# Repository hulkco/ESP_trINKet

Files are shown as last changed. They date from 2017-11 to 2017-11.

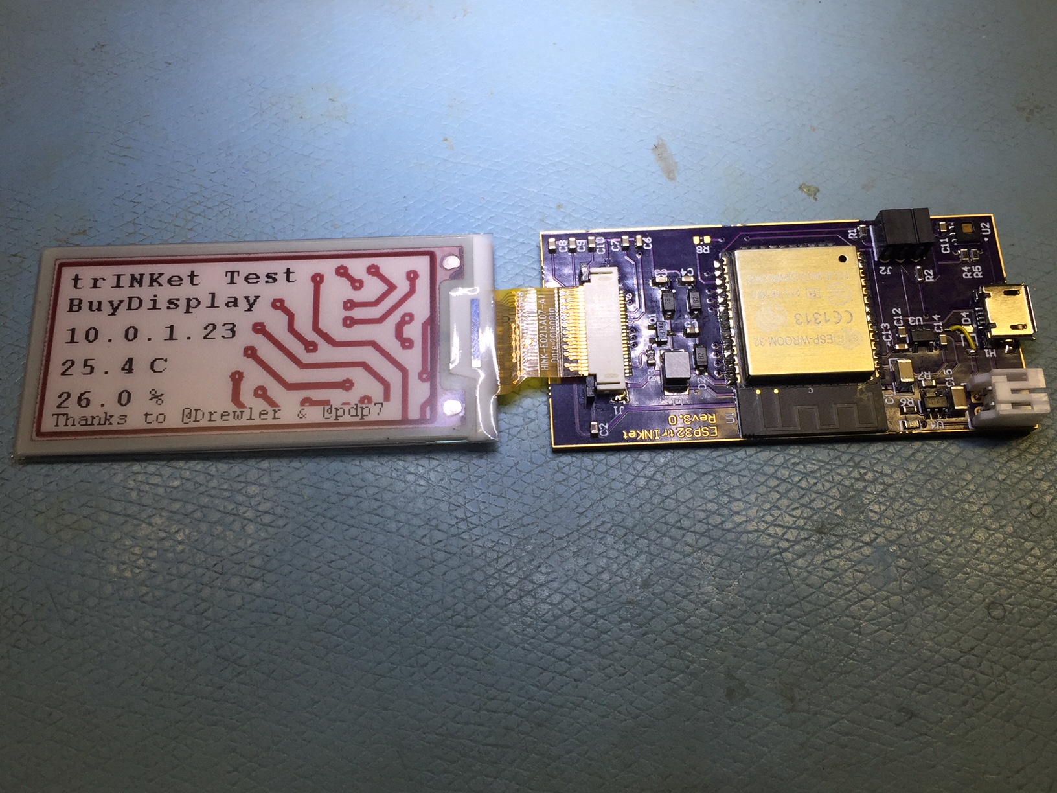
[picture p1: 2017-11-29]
Images/Assembly.JPG

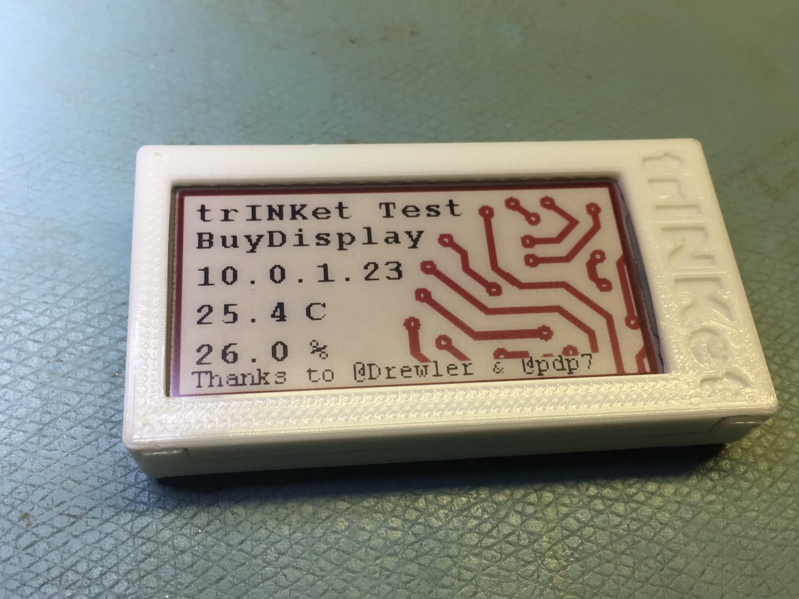
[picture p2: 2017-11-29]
Images/Display.JPG

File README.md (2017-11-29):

# ESP_trINKet
ESP32 E-Ink Developement Board

This design was an experiment using an E-Ink display. Another PCB revision is on the way that should allowing it to be powered from a battery. Right now it can only be powered using a microUSB cable.

The programmer board is located at: https://github.com/mike-rankin/ESP32_Programmer

The enclosure designed in Fusion360 is located here: https://www.thingiverse.com/thing:2675865

Special thanks to:
Drew at OSH Park for supplying the PCB @pdp7
and @drewler for re-writing the Waveshare library so it will work on the BuyDisplay hardware

The code right now does a hardware test verifying the display, sensors and wifi are functional are functional. If you manage to create something of your own I would love to see it by reaching me at @mikerankin

display

board_2

assembly

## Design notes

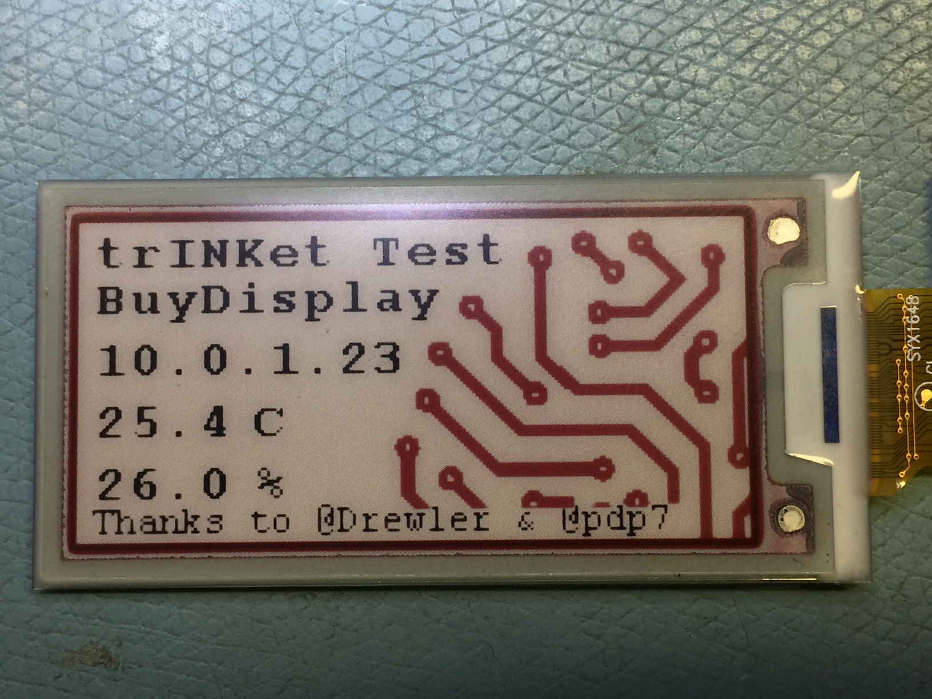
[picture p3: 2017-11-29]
Images/Bare_Display_1.JPG

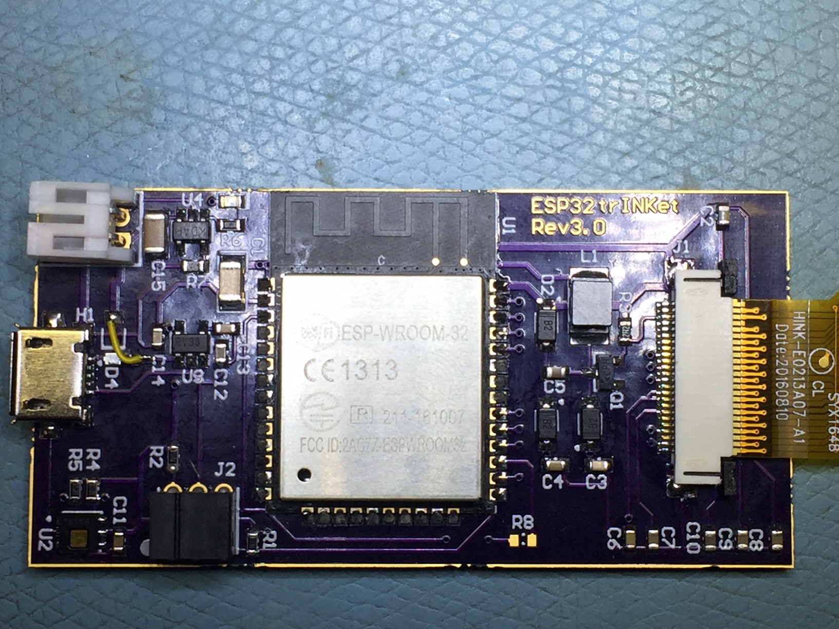
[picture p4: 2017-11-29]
Images/Board_2.JPG

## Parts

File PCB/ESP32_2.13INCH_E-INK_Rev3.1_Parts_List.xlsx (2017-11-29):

Designator | Quantity | Value | Vendor | PartNumber | Description | Manufacturer | Comment
U4 | 1 | MCP73831T-2ACI | Digi-Key | MCP73831T-2ACI/OT | Charger IC Lithium-Ion/Polymer SOT23-5 | Microchip | MCP73831T-2ACI/OT
U3 | 1 | CAT6219-330TDGT3 | Digi-Key | CAT6219-330TDGT3 | IC REG LDO 3.3V 0.5A SOT23-5 | On Semi | CAT6219-330TDGT3
U2 | 1 | 2N7002K-T1-E3 | Digi-Key | 2N7002K-T1-E3 | Humidity/Temperature Sensor | Texas Instruments | HDC1080DMBT
U1 | 1 | ESP32 | Alexpress | ESP32S | WIFI&Bluetooth |  | ESP32s
R6 | 1 | 2K | Digi-Key | ERJ-3EKF2001V | RES SMD 2K OHM 1% 1/10W 0603 | Panasonic | 2K
R4, R5 | 2 | 4.7K | Digi-Key | ERJ-PA3F4701V | RES SMD 4.7K OHM 1% 1/4W 0603 | Panasonic | 4.7K
R3 | 1 | 2.2R | Digi-Key | ERJ-3GEYJ2R2V | RES SMD 2.2 OHM 5% 1/10W 0603 | Panasonic | 2.2R
R1, R2, R7 | 3 | 10K | Digi-Key | ERJ-3EKF1002V | RES SMD 10K OHM 1% 1/10W 0603 | Panasonic | 10K
Q1 | 1 | N-CH Mosfet | Digi-Key | 2N7002K-T1-E3 | MOSFET N-CH 60V 300MA SOT-23 | Vishay Siliconix | 2N7002K-T1-E3
L1 | 1 | 68uH | Digi-Key | LQH43CN680K03L | INDUCTOR 68UH 10% 220MA 1812 | Murata | LQH43CN680K03L
J3 | 1 | Batt Connector | Digi-Key | S2B-PH-K-S(LF)(SN) | CONN HEADER PH SIDE 2POS 2MM | JST | JST
J2 | 1 | 3x2 Female Con | Digi-Key | 0872640652 | Recptacle, Female 3X2,TH, 2MM R/A | MOLEX | 3x2
J1 | 1 | 24POS Flex Con | Digi-Key | 0524352471 | CONN FFC TOP 24POS 0.50MM R/A | Molex | 24POS Flex Con
H3 | 1 | 2.13" E-INK Display | WaveShare | 13368 | WaveShare 2.13" E-INK Display | WaveShare | E-INK Display
H2 | 1 | 2.13" E-INK Display | BuyDisplay | ER-EPD0213-1 | BuyDisplay 2.13" E-INK Display | BuyDisplay | E-INK Display
H1 | 1 | Micro USB | Digi-Key | 1981584-1 | CONN RCPT MICRO USB TYPE AB | TE Connectivity | Micro USB
D5 | 1 | Red | Digi-Key | LTST-C191KRKT | LED RED CLEAR 0603 SMD | Lite-On | LED_0603
D1, D2, D3, D4 | 4 | MBR0520 | Digi-Key | MBR0520-TP | DIODE SCHOTTKY 20V 500MA SOD123 | Micro | MBR0520-TP
C15 | 1 | 10uF | Digi-Key | CL31B106KOHNNNE | CAP CER 10uF 16V 10% X7R 1206 | Samsung | 10uF
C13 | 1 | 10nF | Digi-Key | GRM188R71C103KA01D | CAP CER 0.01uF 16V X7R 0603 | Murata | 10nF
C11 | 1 | 0.1uF | Digi-Key | GRM188R71E104KA01D | CAP, 0.1uF, 25V, 0603 | Murata | 0.1uF
C6, C14 | 2 | 2.2uF | Digi-Key | GRM188R61C225KE15D | CAP CER 2.2uF 16V X5R 0603 | Murata | 2.2uF
C3, C5 | 2 | 1uF | Digi-Key | C0603C105K3RACTU | CAP CER 1UF 25V X7R 0603 | Kemet | 1uF
C2, C4, C7, C8, C9, C10, C12 | 7 | 1uF | Digi-Key | GRM188R71C105KA12D | CAP CER 1uF 16V X7R 0603, CAP CER 1UF 25V X7R 0603, CAP CER 1uF 16V X7R 0603, CAP CER 1uF 16V X7R 0603, CAP CER 1uF 16V X7R 0603, CAP CER 1uF 16V X7R 0603, CAP CER 1uF 16V X7R 0603 | Murata, Kemet, Murata, Murata, Murata, Murata, Murata | 1uF
C1 | 1 | 220uF | Aliexpress | GRM31CC80G227ME11L | CAP CER 220UF 4V X6S 1206 | Murata | 220uF

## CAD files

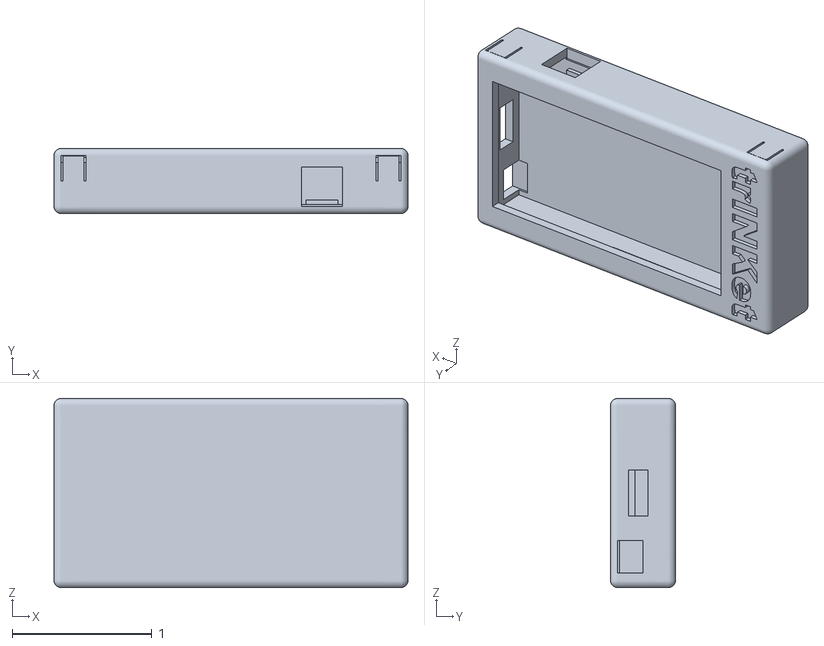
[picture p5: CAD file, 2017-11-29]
Enclosure/trINKet v45.stl
2.53 x 0.465 x 1.35

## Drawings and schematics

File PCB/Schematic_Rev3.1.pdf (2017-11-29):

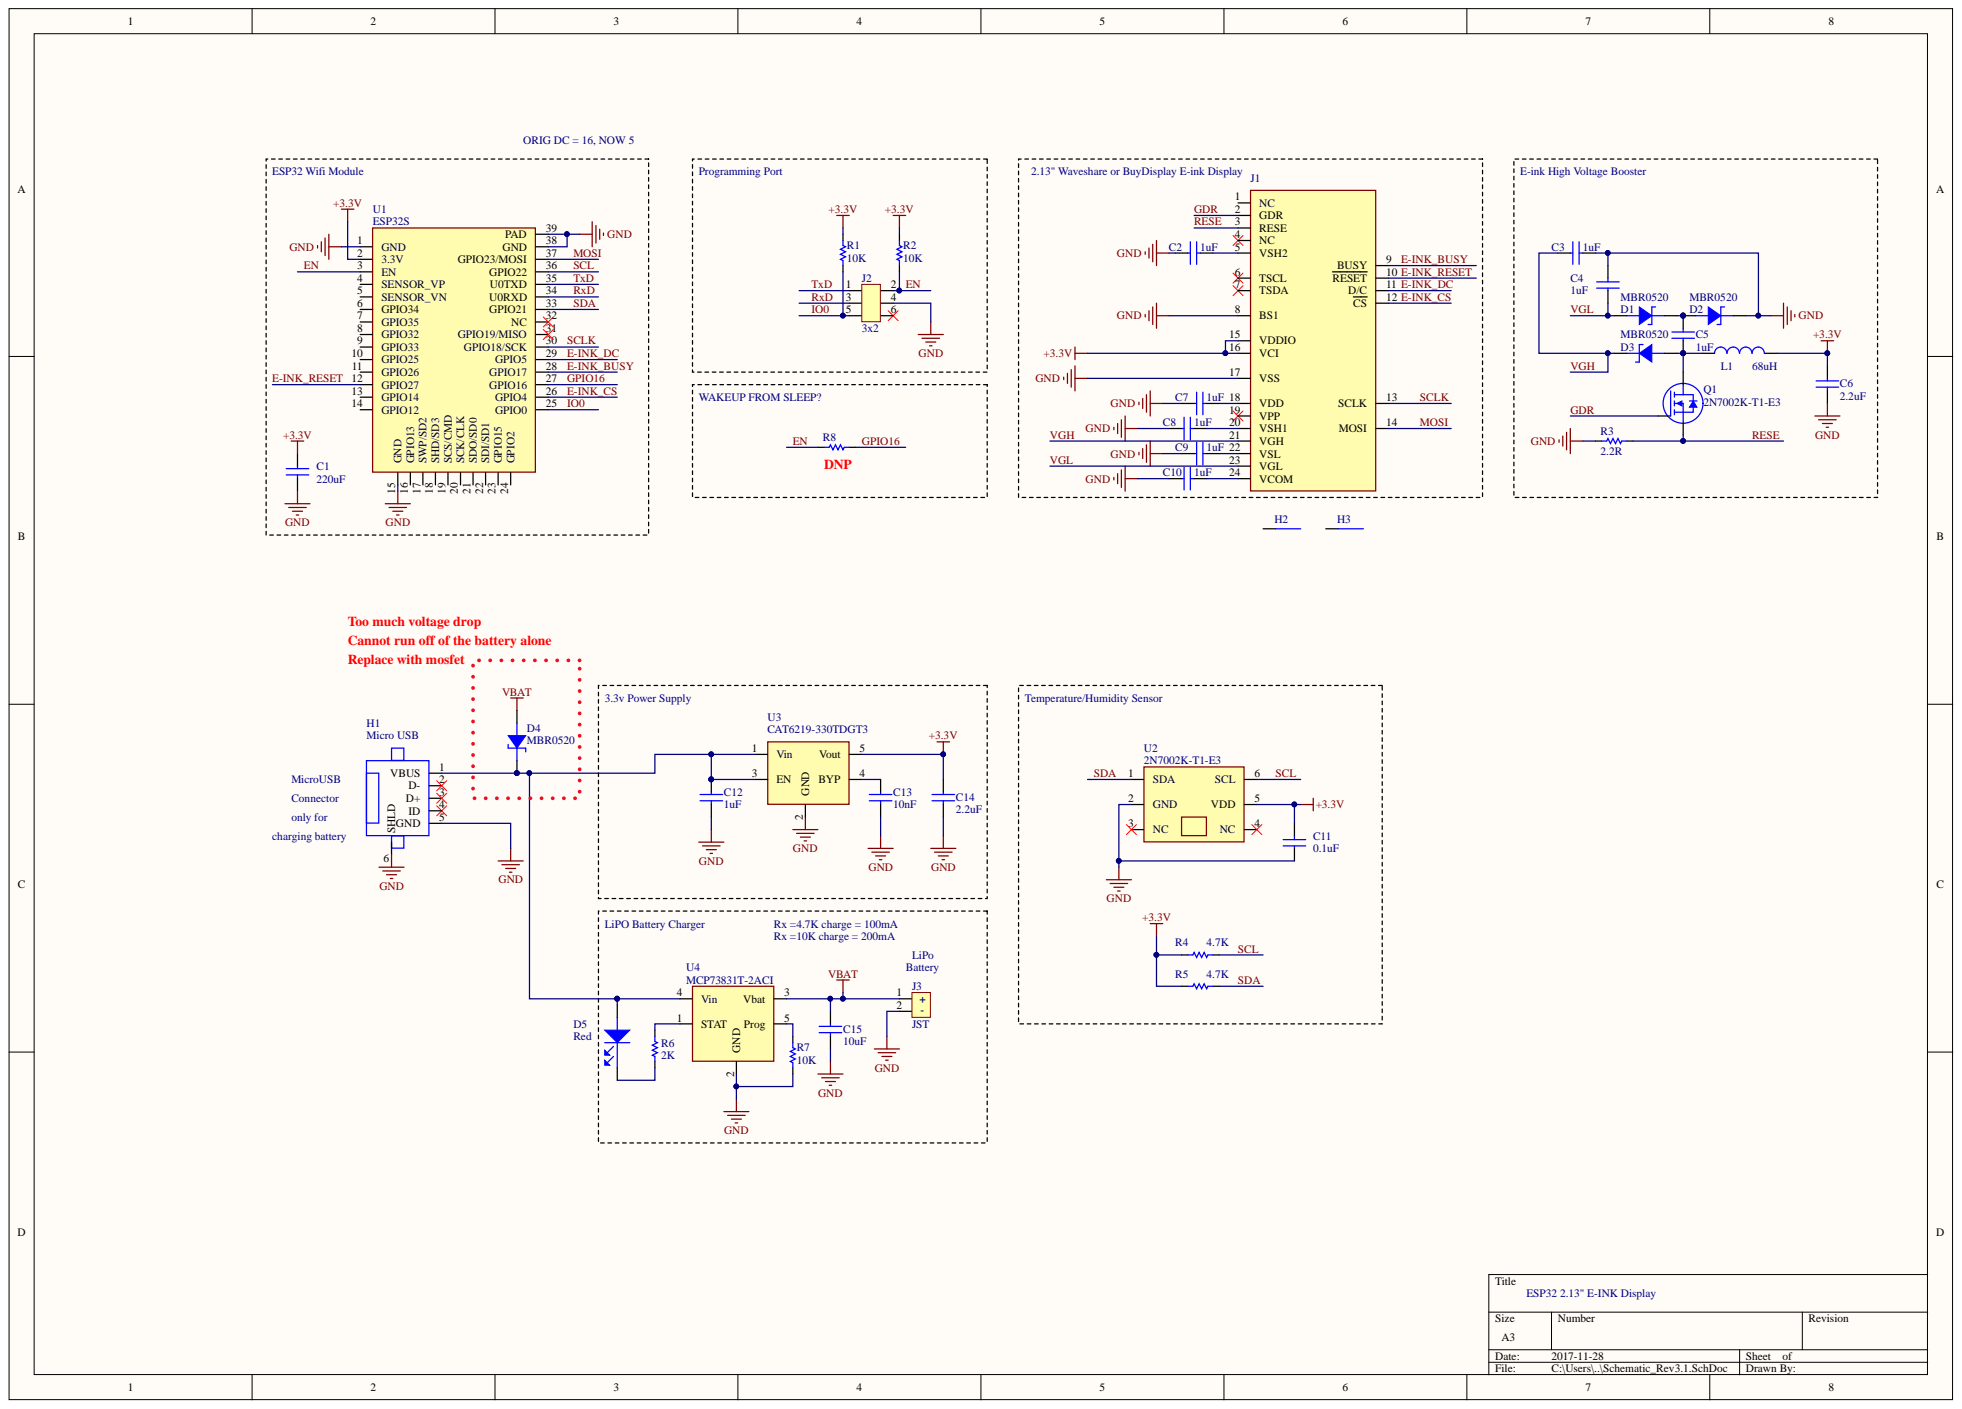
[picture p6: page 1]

Too much voltage drop
Cannot run off of the battery alone
Replace with mosfet

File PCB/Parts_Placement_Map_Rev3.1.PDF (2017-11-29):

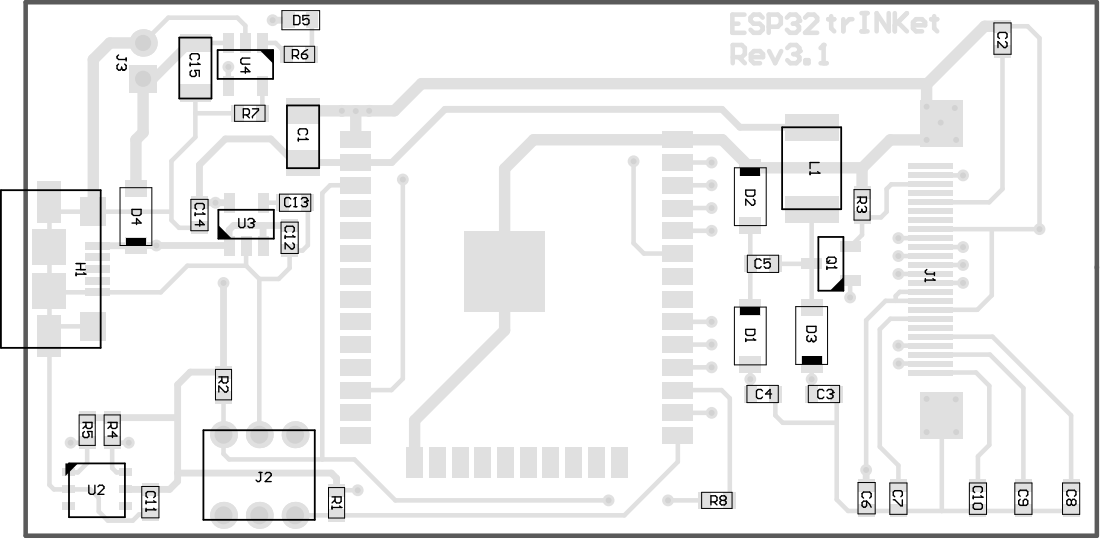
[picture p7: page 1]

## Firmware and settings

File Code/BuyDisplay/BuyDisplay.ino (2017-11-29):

//This is a test sketch for the BuyDisplay E-INK 2.13" hardware using the SSD1675A controller

//Setup
//Arduino File/Preferences/Additional Boards Manager URLs: http://arduino.esp8266.com/versions/2.3.0/package_esp8266com_index.json

//In your Documents/Arduino/Libraries/E-paper folder modify the epdif.h file to
//#define RST_PIN         27 
//#define DC_PIN          5   
//#define CS_PIN          4
//#define BUSY_PIN        17

//Tools/Board/ESP32 Dev Module
//The link for the ESP32 Module install instructions for Windows or a Mac is here: https://github.com/espressif/arduino-esp32/
//You may have to enter http://arduino.esp8266.com/stable/package_esp8266com_index.json into the Arduino IDE under File, Preferences, Additional Board Manager URLs.

//Display Library: https://github.com/drewler/epd

//Create a folder in your Documents/Arduino/Library folder and the contents of epd/src & epdpaint/src into that one folder

#include <WiFi.h>
#include <SPI.h>
#include <epd.h>
#include <epdpaint.h>
#include "imagedata.h"
#include <Wire.h> 
#include "ClosedCube_HDC1080.h"

#define COLORED     0
#define UNCOLORED   1

char ssid[] = "Turd";         // your network SSID (name)
char pass[] = "catinthehat";  // your network password
int status = WL_IDLE_STATUS;  // the Wifi radio's status

ClosedCube_HDC1080 hdc1080;
Epd epd;

void setup() 
{
  Serial.begin(9600);
  hdc1080.begin(0x40);
  
  if (epd.Init() != 0) 
  {
   Serial.print("e-Paper init failed");
   return;
  }
  Serial.print("e-Paper init success\n");

  while (status != WL_CONNECTED) 
  {
   Serial.print("Attempting to connect to WPA SSID: ");
   Serial.println(ssid);
   status = WiFi.begin(ssid, pass);  //Connect to WPA/WPA2 network:
   delay(5000);                      //has to be 5 seconds
 }
   Serial.print("You're connected to the network");
}

void loop() 
{
  char temp[]= "****";
  char humid[]= "****";
  char IP[]= "***.***.***.***";

  epd.ClearFrame();
  
  unsigned char image[3072];    
  Paint paint(image,248,64);    
  
  paint.SetWidth(104);  
  paint.SetHeight(212); 
   
  paint.SetRotate(1);   
 
  paint.Clear(UNCOLORED);

  paint.DrawStringAt(5, 5, "trINKet Test", &Font16, COLORED);
  paint.DrawStringAt(5, 20, "BuyDisplay", &Font16, COLORED);

  epd.DisplayFrame(IMAGE_BLACK, IMAGE_RED);  //Image 
  
  //First Line
  IPAddress ip = WiFi.localIP();
  ip.toString().toCharArray(IP, 16); 
  paint.DrawStringAt(5, 40, IP, &Font16, COLORED); 
                                        
  //Second Line
  float temperature = hdc1080.readTemperature();
  dtostrf(temperature,4,1,temp);                          
  paint.DrawStringAt(5, 60, temp, &Font16, COLORED); //over,down 
  paint.DrawStringAt(55, 60, "C", &Font16, COLORED); 
                      
  //Third Line
  float humidity = hdc1080.readHumidity();
  dtostrf(humidity,4,1,humid);             
  paint.DrawStringAt(5, 80, humid, &Font16, COLORED);
  paint.DrawStringAt(55, 80, "%", &Font16, COLORED); 

  //Fourth Line
  paint.DrawStringAt(5, 93, "Thanks to @Drewler & @pdp7", &Font12, COLORED); 
                        
  epd.SetPartialWindowBlack(paint.GetImage(),0, 0, paint.GetWidth(), paint.GetHeight());  //down,over 0,0

  epd.DisplayFrame();
  delay(30000);
  
  //epd.Sleep();  //Sleep forever...
}

void printWifiData() 
{
  IPAddress ip = WiFi.localIP();
  Serial.print("IP Address: ");
  Serial.println(ip);
  Serial.println(ip);
}

void printCurrentNet() 
{
  Serial.print("SSID: ");
  Serial.println(WiFi.SSID());

  // print the received signal strength:
  long rssi = WiFi.RSSI();
  Serial.print("signal strength (RSSI):");
  Serial.println(rssi);
}
